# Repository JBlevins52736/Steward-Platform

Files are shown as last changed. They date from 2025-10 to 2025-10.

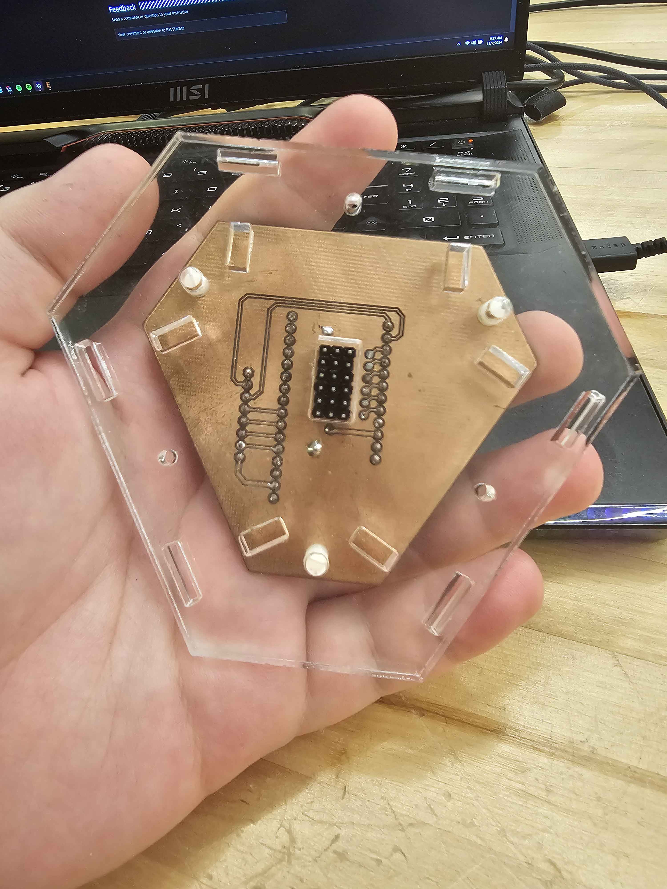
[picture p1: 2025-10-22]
media/images/20241107_091743.jpg

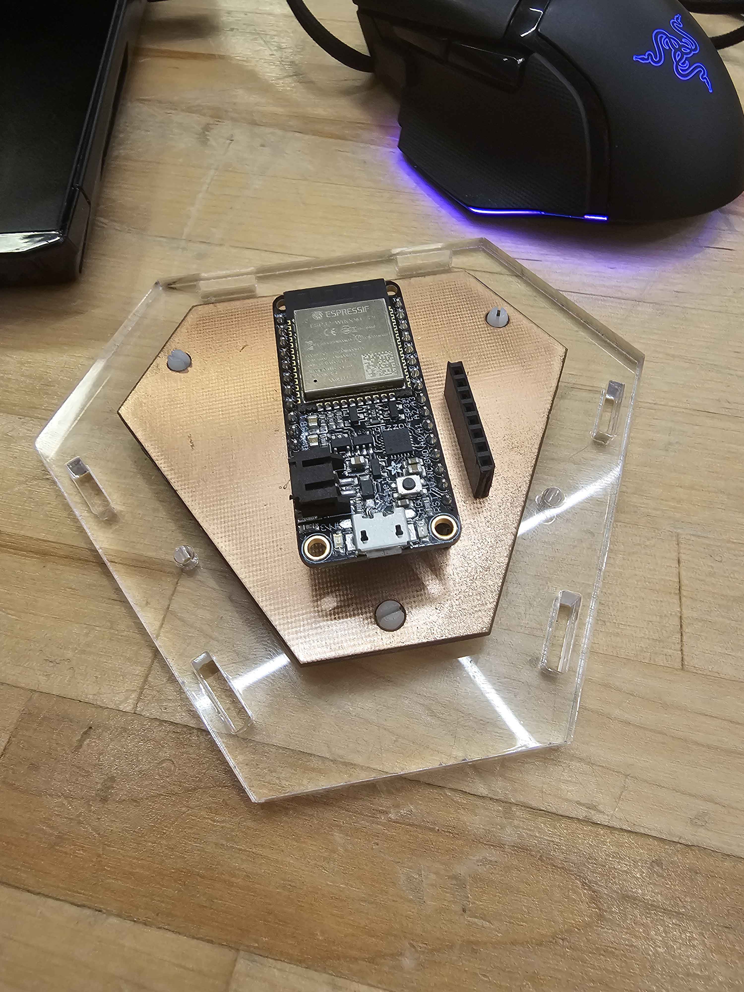
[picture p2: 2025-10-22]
media/images/20241107_091728.jpg

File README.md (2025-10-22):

# Stewart Platform - 6-DOF Parallel Manipulator

A mechanical design project for a Stewart Platform (Gough-Stewart platform) featuring 6 degrees of freedom motion using MG90S micro servo actuators.

## Overview

The Stewart Platform is a parallel manipulator with six prismatic actuators, commonly used in flight simulators, vehicle simulators, and precision positioning systems. This design provides full 6-DOF motion capability: translation along X, Y, Z axes and rotation around all three axes (roll, pitch, yaw).

## Project Structure

```
Steward-Platform/
├── cad/
│   ├── parts/          # Individual component parts (.SLDPRT)
│   ├── assemblies/     # Full assembly files (.SLDASM)
│   └── drawings/       # Technical drawings (.SLDDRW)
├── firmware/           # ESP32 Arduino code
├── electronics/        # Circuit board design files (EagleCAD/EasyEDA)
├── docs/               # Documentation and specifications
├── media/
│   ├── images/         # Renders, textures, and decals
│   ├── videos/         # Motion simulation videos
│   └── hdri/           # HDR environment maps for rendering
└── README.md
```

## Key Components

### Platform Structure
- **Top Plate** - Moving platform (upper)
- **Bottom Plate** - Fixed base (lower)
- **Middle Plate** - Intermediate structural support
- **Circuit Board** - Electronics mounting

### Actuation System
- **MG90S Micro Servos** (6x) - 9g hobby servos for actuation
- **Servo Horns** - Attachment points for linkages
- **Rods/Links** - Connecting elements between servos and platform
- **Ball Links** - Universal joints for full range of motion

### Electronics & Control
- **ESP32 Microcontroller** - Controls all 6 servos with 12 DOF motion patterns
- **Custom PCB** - Circuit board design available in `electronics/`
- **Firmware** - Arduino-based control code in `firmware/StewartPlatform.ino`

## Software Requirements

### CAD Software
- **SolidWorks** - Required to open and edit:
  - `.SLDPRT` - Part files
  - `.SLDASM` - Assembly files
  - `.SLDDRW` - Drawing files

### Firmware Development
- **Arduino IDE** with ESP32 board support
- **Required Libraries**:
  - ESP32Servo.h
- **Board Packages**:
  - `https://adafruit.github.io/arduino-board-index/package_adafruit_index.json`
  - `https://espressif.github.io/arduino-esp32/package_esp32_index.json`

### Electronics Design
- **EasyEDA** or compatible PCB design software for viewing/editing circuit board files

## Design Specifications

### Mechanical
- **Actuators**: 6x MG90S micro servos
- **Degrees of Freedom**: 6 (X, Y, Z, Roll, Pitch, Yaw)
- **Architecture**: Parallel manipulator (all actuators work together)
- **Joint Type**: Ball-and-socket/spherical joints
- **Servo Range**: 10° - 170° (configurable in firmware)

### Electronic
- **Controller**: ESP32 microcontroller
- **Servo Control**: 6 independent PWM channels
- **Motion Patterns**: 12 pre-programmed DOF states (Heave, Surge, Sway, Yaw, Pitch, Roll)
- **Calibration**: Individual servo trim adjustment via serial commands
- **Interpolation**: Smooth 500ms transitions between motion states

## Documentation

- `JB_SP_Measurement.xlsx` - Platform measurements and geometry specifications
- `StewartPlatformMotionStudyRubric.xlsx` - Motion study evaluation criteria
- `PrimaryDrawingtemplate.pdf` - Technical drawing template

## Motion Simulation

Motion studies and simulations are performed in SolidWorks Motion Analysis. Example simulation video available in `media/videos/`.

## Development

### Modifying the CAD Design
1. Open `cad/assemblies/JBJBStewardPlatform.SLDASM` in SolidWorks
2. Edit individual parts in the `cad/parts/` directory as needed
3. Verify assembly constraints maintain proper DOF
4. Run motion studies to validate range of motion
5. Update technical drawings if dimensions change
6. Export new servo positions to update firmware motion arrays

### Uploading Firmware
1. Install Arduino IDE with ESP32 board support (see Software Requirements)
2. Install required ESP32Servo library
3. Open `firmware/StewartPlatform.ino`
4. Connect ESP32 via USB
5. Select correct board and COM port
6. Upload to ESP32

### Serial Commands
The firmware supports serial commands for calibration:
- `C` - Get/set calibration mode (C=0 or C=1)
- `T` - Get/set trim for all servos (e.g., T=5)
- `T0` through `T5` - Get/set individual servo trim (e.g., T0=-3)
- `O` - Get/set platform offset (e.g., O=10)

### Best Practices
- Maintain proper assembly constraints for 6-DOF motion
- Verify no singularities in the workspace
- Keep ball joint positions within servo range
- Test full range of motion in simulation before fabrication
- Calibrate servo trim values before running motion sequences
- Use serial monitor at 115200 baud for debugging

## License

See repository license file for details.

## Contributing

Contributions, issues, and feature requests are welcome!

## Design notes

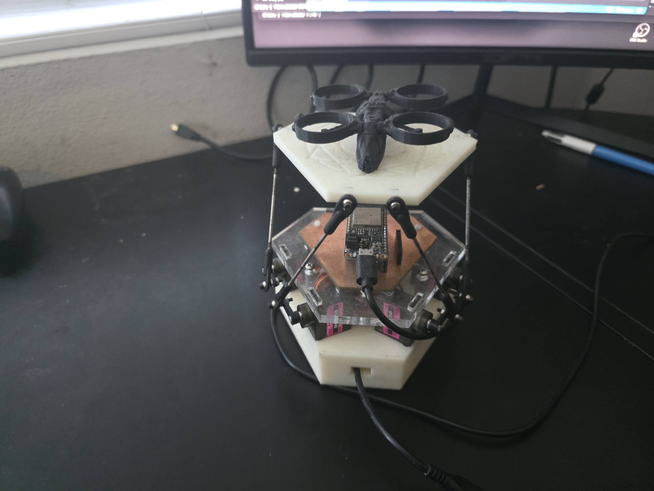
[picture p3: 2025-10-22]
media/images/Screenshot 2025-10-22 172505.png

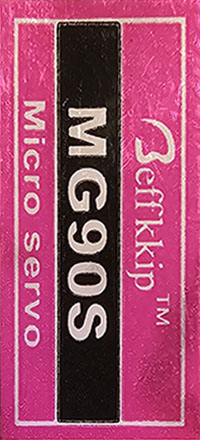
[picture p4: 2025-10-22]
media/images/mg90s micro servo decal.jpg

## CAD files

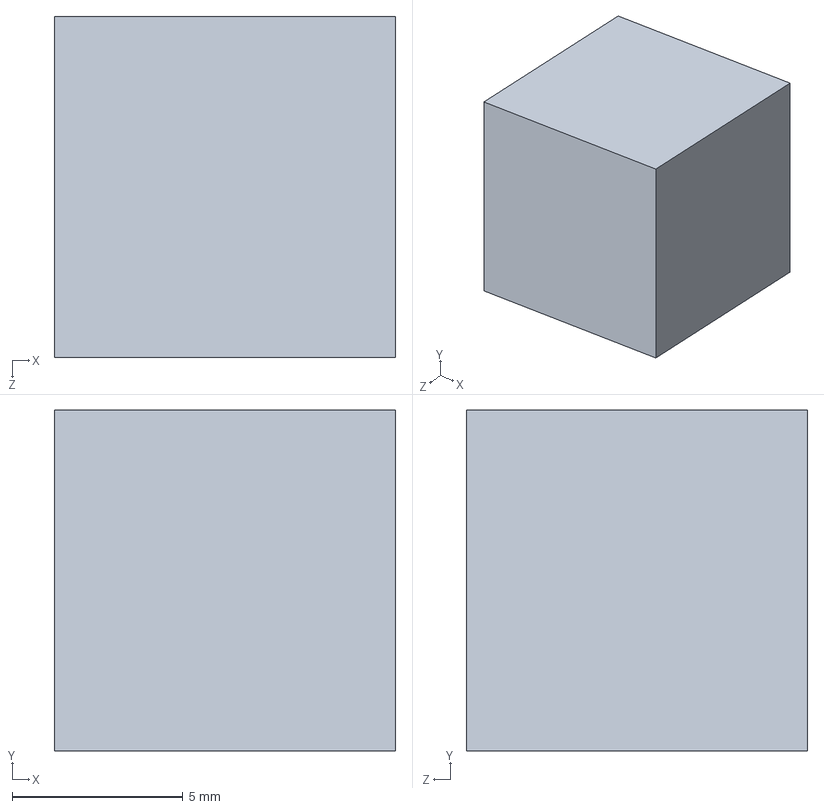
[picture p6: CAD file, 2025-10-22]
cad/parts/JB6dof.SLDPRT
10.0 x 10.00 x 10.0 mm

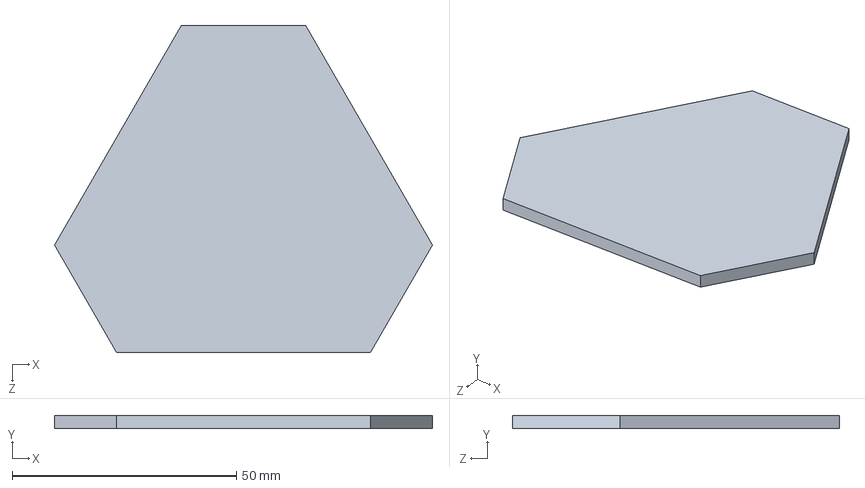
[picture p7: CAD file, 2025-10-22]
cad/parts/JBCircuit_board.SLDPRT
84.2 x 3.00 x 72.9 mm

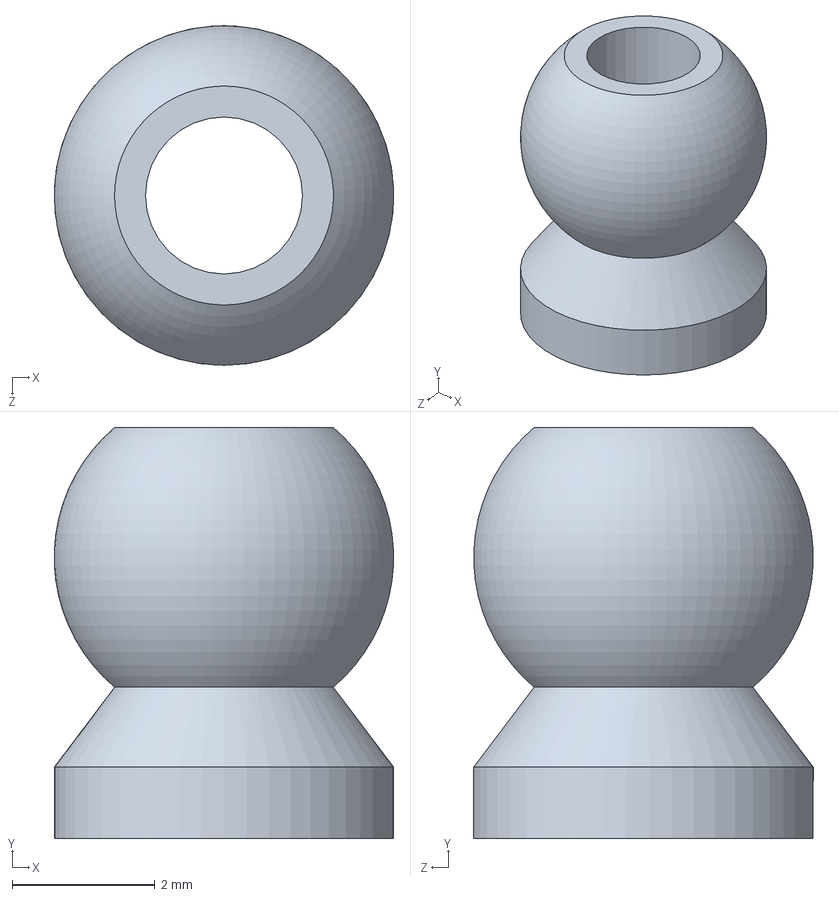
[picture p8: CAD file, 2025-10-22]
cad/parts/JBBalllink.SLDPRT
4.76 x 5.76 x 4.76 mm

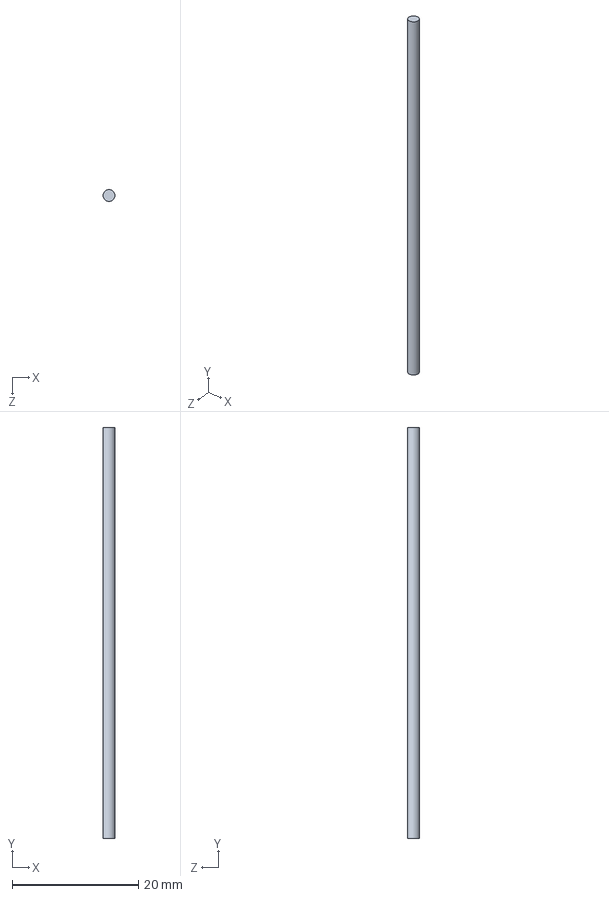
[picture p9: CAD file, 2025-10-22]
cad/parts/JBRod.SLDPRT
1.87 x 65.0 x 1.88 mm

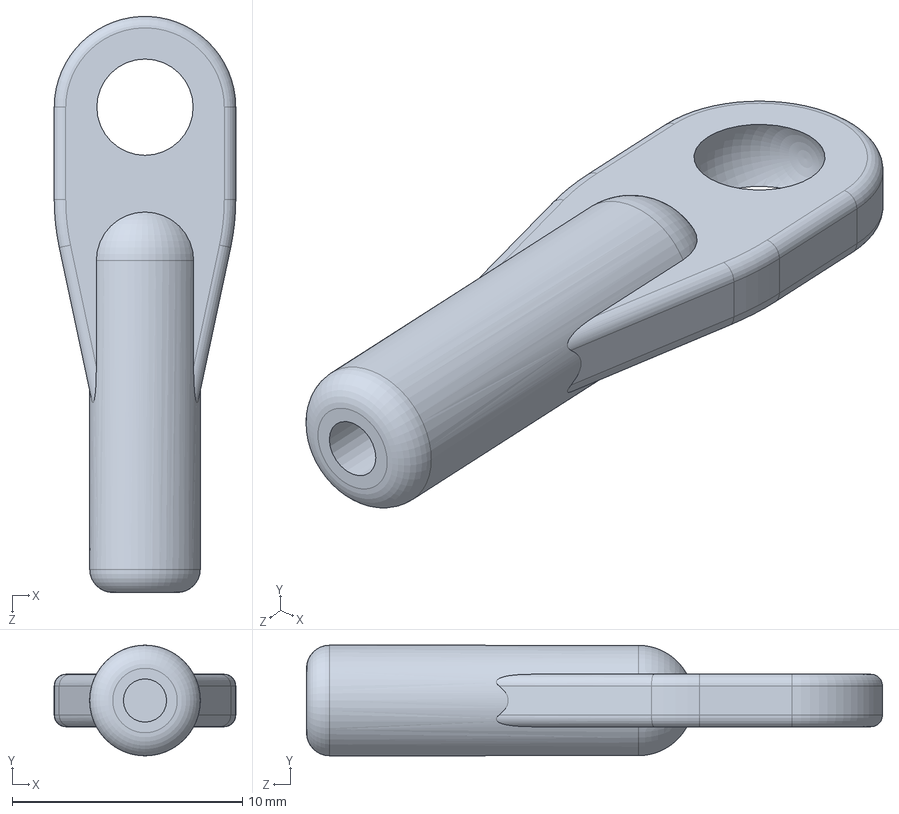
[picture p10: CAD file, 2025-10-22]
cad/parts/JBHousing.SLDPRT
7.88 x 4.80 x 25.0 mm

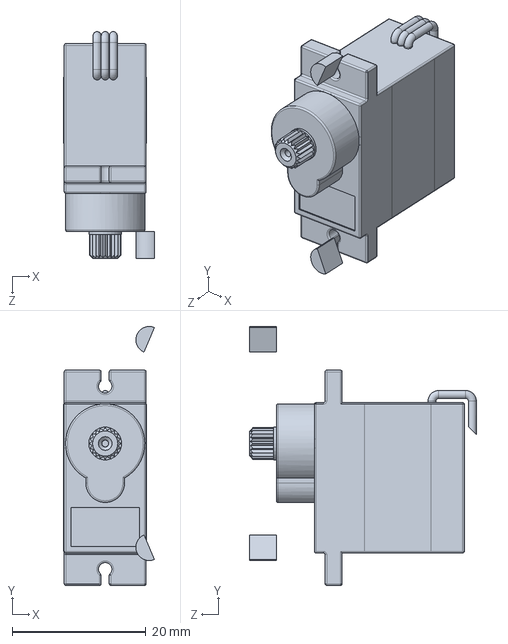
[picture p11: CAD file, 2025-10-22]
cad/parts/JBMG90S Micro Servo.SLDPRT
13.6 x 38.8 x 34.0 mm

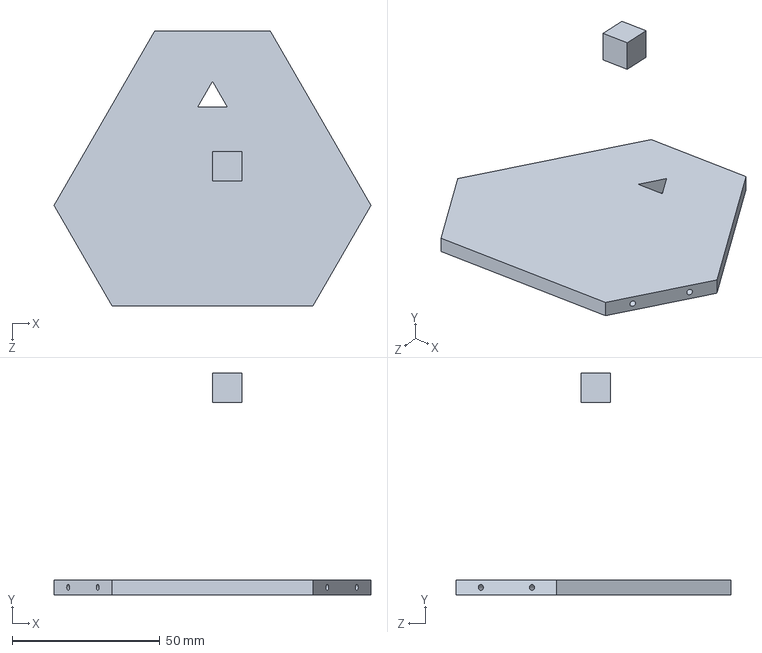
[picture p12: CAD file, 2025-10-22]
cad/parts/JBTop_Plate.SLDPRT
107.3 x 75.0 x 92.9 mm

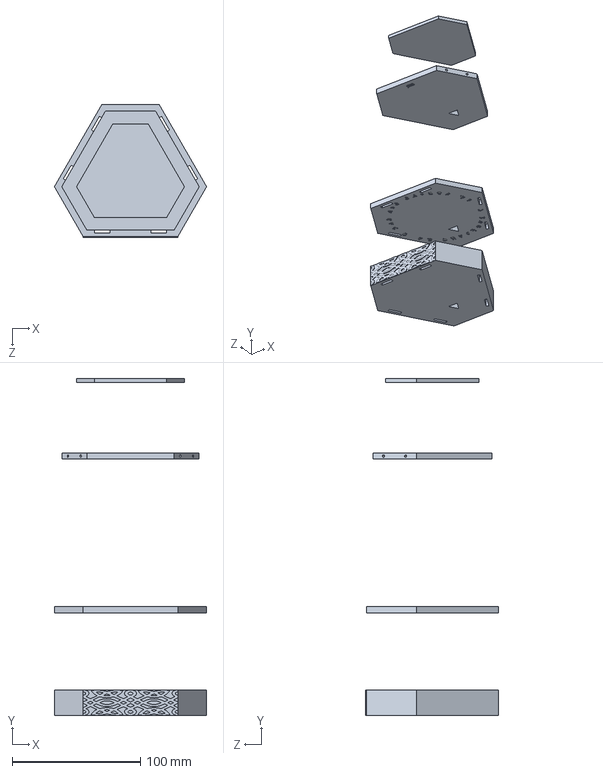
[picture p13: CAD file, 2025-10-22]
cad/parts/JBMASTER.SLDPRT
118.8 x 263.0 x 103.4 mm

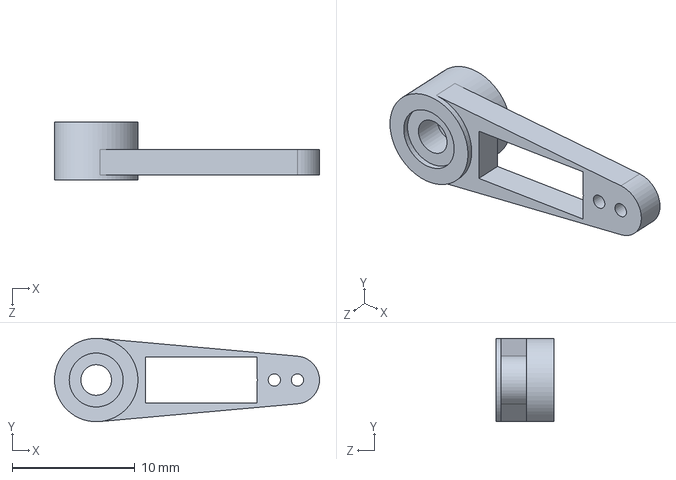
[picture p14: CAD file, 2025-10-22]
cad/parts/JBHorn (MG90S).SLDPRT
21.6 x 6.80 x 4.75 mm

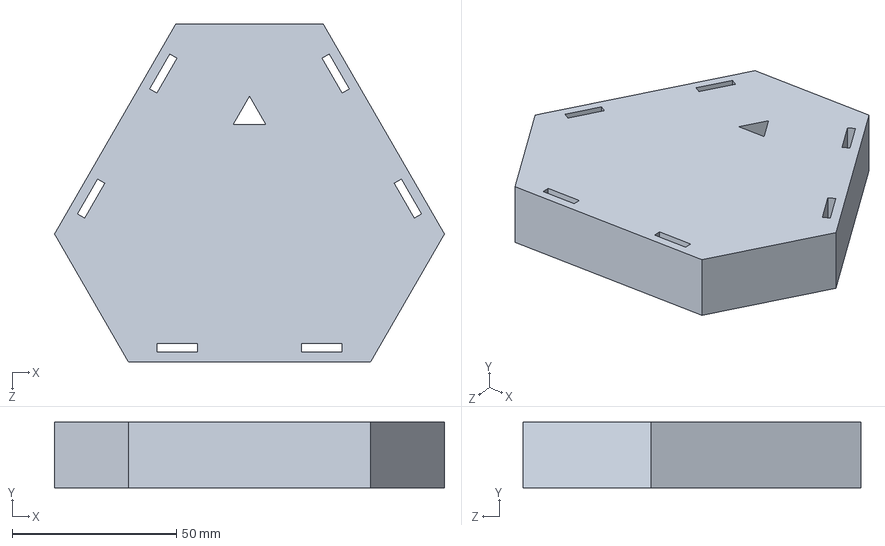
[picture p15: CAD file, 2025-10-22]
cad/parts/JBBottem_Plate.SLDPRT
118.8 x 20.0 x 102.9 mm

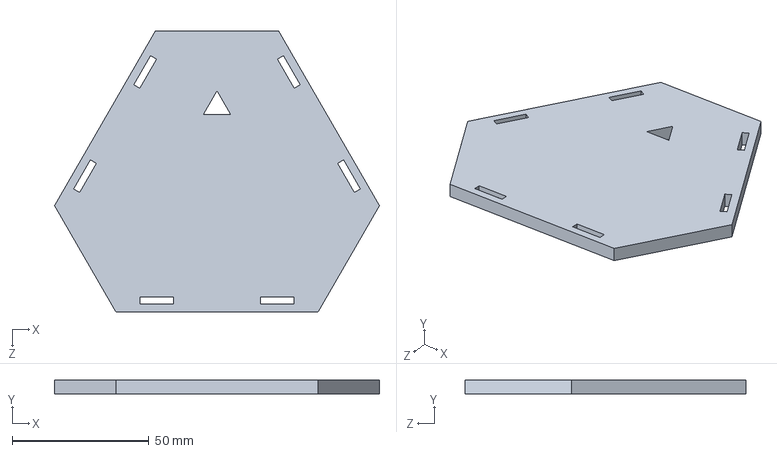
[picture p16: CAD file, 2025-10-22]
cad/parts/JBMiddle_Plate.SLDPRT
118.8 x 5.00 x 102.9 mm

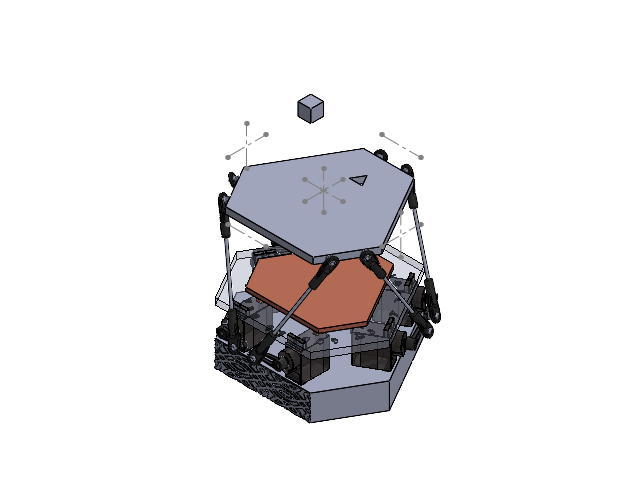
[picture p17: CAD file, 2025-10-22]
cad/assemblies/JBJBStewardPlatform.SLDASM
Bottem_Plate
Middle_Plate
Top_Plate
MG90S Micro Servo x 6
Balllink x 12
Rod x 6
Housing x 12
Horn (MG90S) x 6
6dof
Circuit_board

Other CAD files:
cad/drawings/JBJBStewardPlatform.SLDDRW

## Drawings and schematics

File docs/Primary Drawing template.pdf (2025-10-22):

B B

2

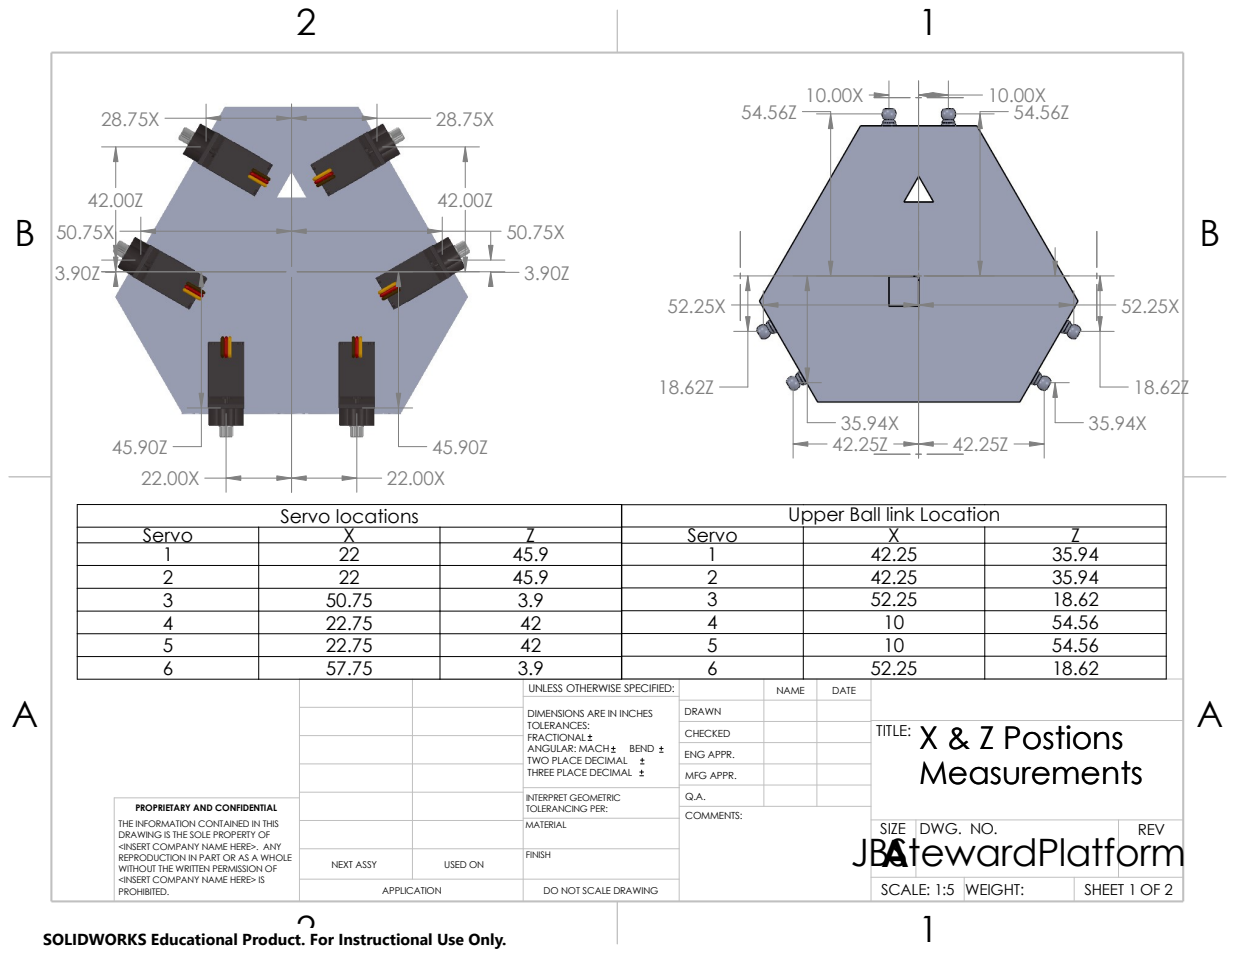
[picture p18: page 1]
COMMENTS:

Servo locations | Upper Ball link Location

Servo | X | Z | Servo | X | Z
1 | 22 | 45.9 | 1 | 42.25 | 35.94
2 | 22 | 45.9 | 2 | 42.25 | 35.94
3 | 50.75 | 3.9 | 3 | 52.25 | 18.62
4 | 22.75 | 42 | 4 | 10 | 54.56
5 | 22.75 | 42 | 5 | 10 | 54.56
6 | 57.75 | 3.9 | 6 | 52.25 | 18.62

UNLESS OTHERWISE SPECIFIED: | | NAME | DATE

DIMENSIONS ARE IN INCHES TOLERANCES: FRACTIONAL ANGULAR: MACH BEND TWO PLACE DECIMAL THREE PLACE DECIMAL | DRAWN

CHECKED | | | X & Z Postions TITLE: Measurements

ENG APPR.
MFG APPR.

INTERPRET GEOMETRIC TOLERANCING PER: | Q.A.
MATERIAL | JBStewardPlatform | SIZE A | DWG. NO. | REV

PROPRIETARY AND CONFIDENTIAL
THE INFORMATION CONTAINED IN THIS
DRAWING IS THE SOLE PROPERTY OF
<INSERT COMPANY NAME HERE>. ANY
REPRODUCTION IN PART OR AS A WHOLE
WITHOUT THE WRITTEN PERMISSION OF
<INSERT COMPANY NAME HERE> IS
PROHIBITED.

NEXT ASSY | USED ON | FINISH

APPLICATION | DO NOT SCALE DRAWING | | SCALE: 1:5 | WEIGHT: | SHEET 1 OF 2

SOLIDWORKS Educational Product. For Instructional Use Only.

124.38

# Center of Ball Joints

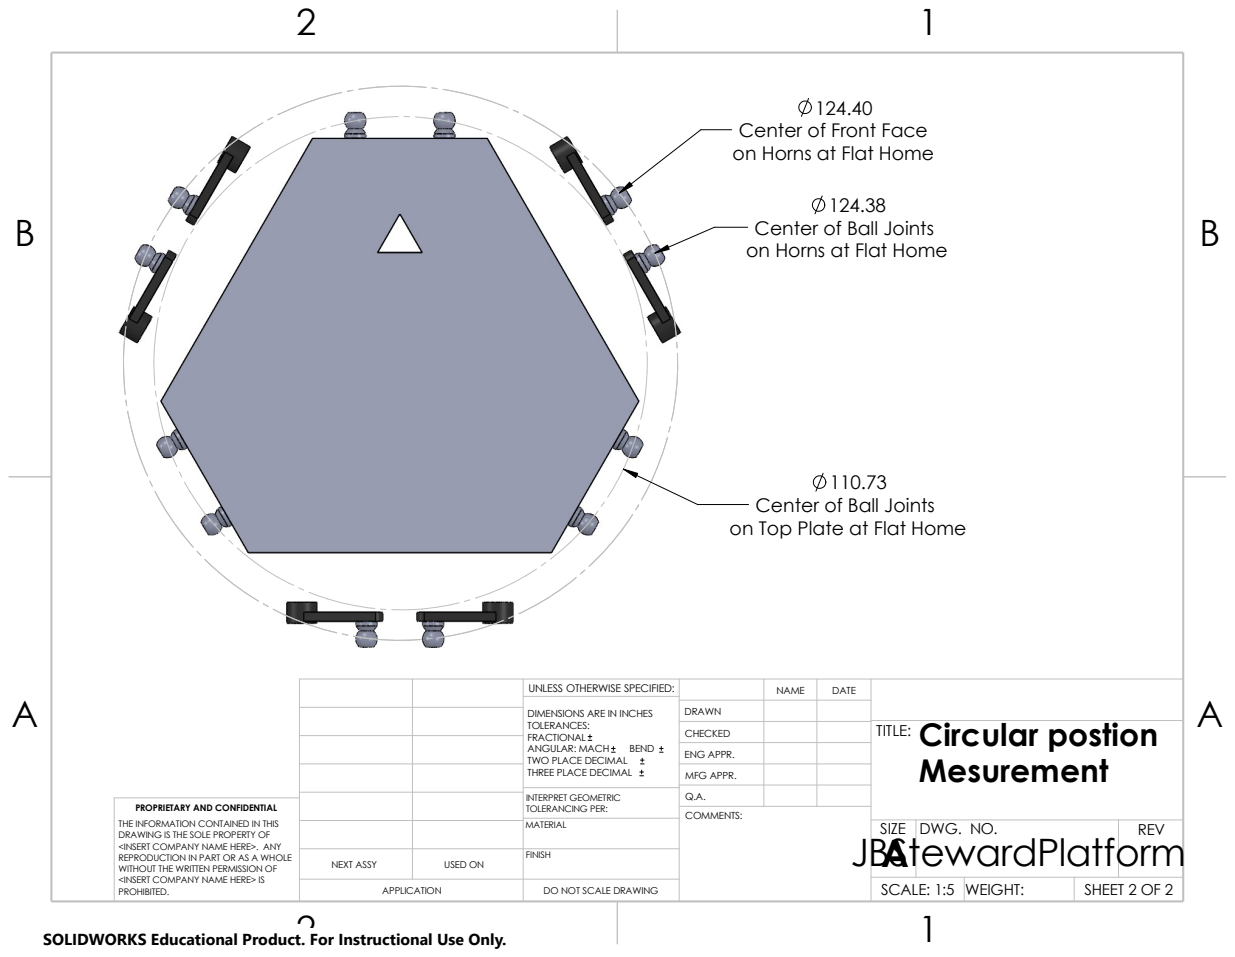
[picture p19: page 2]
COMMENTS:

Center of Front Face
on Horns at Flat Home

Center of Ball Joints
on Top Plate at Flat Home

UNLESS OTHERWISE SPECIFIED: | | NAME | DATE

DIMENSIONS ARE IN INCHES TOLERANCES: FRACTIONAL ANGULAR: MACH BEND TWO PLACE DECIMAL THREE PLACE DECIMAL | DRAWN

CHECKED | | | Circular postion TITLE: Mesurement

ENG APPR.
MFG APPR.

INTERPRET GEOMETRIC TOLERANCING PER: | Q.A.
MATERIAL | JBStewardPlatform | SIZE A | DWG. NO. | REV

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

NEXT ASSY | USED ON | FINISH

APPLICATION | DO NOT SCALE DRAWING | | SCALE: 1:5 | WEIGHT: | SHEET 2 OF 2

SOLIDWORKS Educational Product. For Instructional Use Only.

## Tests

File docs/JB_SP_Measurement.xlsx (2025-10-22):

 | NO COLLISION |  |  |  |  |  |  |  |  | COLLISION
 | Heave(Y) | Surge(Z) | Sway(X) | Yaw(Y) | Pitch(X) | Roll(Z) |  |  |  | Heave(Y) | Surge(Z) | Sway(X) | Yaw(Y) | Pitch(X) | Roll(Z)
 | 14.3 | 22.66 | 21.6 | 22.79 | 14.5 | 15 |  |  |  | 13.85 | 22.66 | 20.6 | 21.35 | 14.6 | 12.7
Home | 0 | 0 | 0 | 0 | 0 | 0 |  |  | Home | 0 | 0 | 0 | 0 | 0 | 0 |  |  | 61.85
 | 15.86 | 24.4 | 21.6 | 22.79 | 16.67 | 15 |  |  |  | 11.5 | 21.4 | 20.6 | 21.35 | 11.9 | 12.7
Symmetry | SYM |  | SYM | SYM |  | SYM |  |  |  | SYM |  | SYM | SYM |  | SYM
 |  |  |  |  |  |  |  |  |  |  | check nb |  |  | check nb
 | OFFSET | 23.01
Angled Home |  | Heave |  |  |  | Surge |  |  |  | Sway |  |  |  | Yaw |  |  |  | Pitch |  |  |  | Roll
Servo | Start Angle | 1 | 2 | 3 | 4 | 5 | 6 | 7 | 8 | 9 | 10 | 11 | 12 | 13 | 14 | 15 | 16 | 17 | 18 | 19 | 20 | 21 | 22 | 23 | 24
1 | 90 | 25.35 |  | 135.82 |  | 64.67 |  | 125.91 |  | 135.26 |  | 73.6 |  | 59.86 |  | 152.27 |  | 59.38 |  | 118.09 |  | 124.79 |  | 51.38
2 | 90 | 154.65 |  | 44.18 |  | 132.98 |  | 113.03 |  | 44.74 |  | 106.32 |  | 121.14 |  | 125.02 |  | 120.62 |  | 61.91 |  | 128.5 |  | 55.11
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

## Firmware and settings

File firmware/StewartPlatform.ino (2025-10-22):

/****
Required Arduino hardware packages:
https://adafruit.github.io/arduino-board-index/package_adafruit_index.json
https://espressif.github.io/arduino-esp32/package_esp32_index.json

Required Libraries:
Arduino ESP32Servo.h

****/

// includes
#include <ESP32Servo.h>

// macros
#define NUM_SERVOS 6
#define MIN_SERVO_POS 10
#define MID_SERVO_POS 90
#define MAX_SERVO_POS 170
#define TIMESTAMP_PERIOD 500
#define NUM_PLATFORM_STATES 24

// structs
typedef struct 
{
  uint8_t pin;
  int8_t trim;
  float offset;
  uint8_t last;
  uint8_t next;
} SERVO_DATA;

// globals
bool calibrate = false;
uint32_t timestamp = 0;
int8_t platform_offset = 0;
uint8_t platform_state = 0;

/*****************/
/**** TODO #1 ****/
/*****************/

// create/initialize 6x array of servo objects
Servo servos[NUM_SERVOS];

// create/initialize 6x array of SERVO_DATA (pin=?, trim=0, last=90, next=90)
SERVO_DATA sdat[NUM_SERVOS] = {
  {pin: 14, trim: 7, offset:-23.01, last: MID_SERVO_POS, next: MID_SERVO_POS},
  {pin: 32, trim: -7, offset:23.01, last: MID_SERVO_POS, next: MID_SERVO_POS},
  {pin: 15, trim: 6, offset:-23.01, last: MID_SERVO_POS, next: MID_SERVO_POS},
  {pin: 33, trim: 0, offset:23.01, last: MID_SERVO_POS, next: MID_SERVO_POS},
  {pin: 27, trim: 10, offset:-23.01, last: MID_SERVO_POS, next: MID_SERVO_POS},
  {pin: 12, trim: 3, offset:23.01, last: MID_SERVO_POS, next: MID_SERVO_POS}
};

// create/initialize 24x6 array of DOF platform positions from Solidworks simulation (heave, surge, sway, yaw, pitch, roll)
float platform_positions[NUM_PLATFORM_STATES][NUM_SERVOS] = {
  
   // Initial state (Home position for all servos)
  // {60, 60, 60, 60, 60, 60},
  // {90, 90, 90, 90, 90, 90},
  // {120, 120, 120, 120, 120, 120}

  // Heave positions 
  {25.35, 154.65, 25.35, 154.65, 25.35, 154.65}, // State 1
  {90, 90, 90, 90, 90, 90}, 
  {135.82, 44.18, 135.82, 44.18, 135.82, 44.18}, // State 2
  {90, 90, 90, 90, 90, 90},
  // Surge positions 
   {73.49, 132.98, 125.68, 83.79, 96.21, 22.11}, // State 3
   {90, 90, 90, 90, 90, 90}, 
   {137.74, 42.26, 22.17, 62.49, 117.51, 125.68}, // State 4
   {90, 90, 90, 90, 90, 90}, 

  // Sway positions
  {64.21, 45.35, 85.14, 121.15, 150.44, 108.64},  // State 5
  {90, 90, 90, 90, 90, 90}, 
  {135.65, 115.79, 108.64, 29.56, 58.85, 85.14},    // State 6
  {90, 90, 90, 90, 90, 90}, 

  // Yaw positions 
  {115.79, 121.14, 115.79, 121.14, 115.79, 121.14},   // State 7
  {90, 90, 90, 90, 90, 90}, 
  {27.73, 54.98, 27.73, 54.98, 27.73, 54.98}, // State 8
  {90, 90, 90, 90, 90, 90}, 
  

  // Pitch positions
  {58.68, 121.32, 70.94, 24.43, 152.04, 109.06}, // State 9
  {90, 90, 90, 90, 90, 90}, 
  {118.09, 61.91, 104.18, 136.99, 43.12, 75.82},  // State 10
  {90, 90, 90, 90, 90, 90}, 

  // Roll positions 
  {124.79, 128.5, 45.19, 95.94, 97.36, 42.57},    // State 11
  {90, 90, 90, 90, 90, 90}, 
  {51.38, 55.11, 137.61, 82.62, 84.05, 134.96},   // State 12
  {90, 90, 90, 90, 90, 90}  
};
// process KVP (KEY=VAL)
String procKVP(String skvp)
{
  String sret;
	bool rv = true;

	if (skvp.length())
	{
    skvp.toUpperCase();

		int16_t z = skvp.indexOf("=");
    if (z == -1) z = skvp.length();
		String skey = skvp.substring(0, z);
		String sval = skvp.substring(z + 1);
		uint32_t ival = sval.toInt();
		float fval = sval.toFloat();

		//****************************//
		//***** sval length == 0 *****//
		//****************************//
		if (sval.length() == 0)
		{
      // set calibration mode
			if (skey == "C") sval = String(calibrate);

      // print trim all servos
      else if (skey == "T")
      {
        for (uint8_t i = 0; i < NUM_SERVOS; i++)
        {
          sval += " ";
          sval += String(sdat[i].trim);
        }
      }

      // print trim specific servo
      else if (skey[0] == 'T')
      {
        int8_t i = skey[1] - 48;
        if ((i  < 0) || (i >= NUM_SERVOS)) rv = false;
        else sval = String(sdat[i].trim);
      }

      // print offset all servos
      else if (skey == "O") sval  = String(platform_offset);

      // else error
			else rv = false;
		}

		//*********************************//
		//***** else sval length != 0 *****//
		//*********************************//

    // set calibration state
    else if (skey == "C") calibrate = ival;

    // set trim all servos
    else if (skey == "T") {for (uint8_t i = 0; i < NUM_SERVOS; i++) sdat[i].trim = ival;}

    // set trim specific servo
    else if (skey[0] == 'T')
    {
      int8_t i = skey[1] - 48;
      if ((i  < 0) || (i >= NUM_SERVOS)) rv = false;
      else sdat[i].trim = ival;
    }

    // set offset all servos
    else if (skey == "O") platform_offset = ival;

    // else error
		else rv = false;

    // if command OK
		if (rv == true)
		{
			if (sval.length()) sret = skey + "=" + sval + " OK";
			else sret = skey + " OK";
		}

    // else command ER
    else sret = skvp + " ER";

    Serial.println(sret);
	}

	return(sret);
}

// read KVP
String readKVP(void)
{
	bool rv = false;
	static uint8_t x = 0;
	static String sstr = "";

	if (x == 0) sstr = "";

	while (Serial.available())
	{
		char c = (char)Serial.read();
		if ((c == '\r') || (c == '\n'))
		{
			x = 0;
			rv = true;
			break;
		}

		x++;
		sstr += c;
	}

	return(rv ? sstr : String(""));
}

void setup()
{
  
  /*****************/
  /**** TODO #2 ****/
  /*****************/
  
  // initialize serial object
  Serial.begin(115200);
  
  // wait for terminal to open
  while(!Serial || (millis() <= 5000));
 

  // Attach each servo to its corresponding pin and set to MID_SERVO_POS (90 degrees)
  for (int i = 0; i < NUM_SERVOS; i++) {
    servos[i].attach(sdat[i].pin);      
    servos[i].write(MID_SERVO_POS+sdat[i].trim  + sdat[i].offset);     

  Serial.println("setup() complete");
}

void loop()
{
  // capture timenow in milliseconds
    uint32_t timenow = millis();
  // process commands
  procKVP(readKVP());
  
  /*****************/
  /**** TODO #3 ****/
  /*****************/

  // if calibrating servo trim
  if (calibrate) 
  {
	   for (int i = 0; i < NUM_SERVOS; i++) {
      // Set servo position to 90 degrees plus its trim value, constrained to the defined limits
      float pos = constrain(MID_SERVO_POS + sdat[i].trim - sdat[i].offset , MIN_SERVO_POS, MAX_SERVO_POS);
      servos[i].write(pos);
    }
    return;
  }

  /*****************/
  /**** TODO #5 ****/
  /*****************/

  // calculate ratio of timenow to timestamp relative 500ms period
  // for all servos
    // calculate lerped position between last and next using ratio
    // write servo to lerped position, use contrain() to limit range.
  float ratio = float(timenow - timestamp) / TIMESTAMP_PERIOD;


  // Print the interpolation ratio for debugging
  Serial.print("Interpolation ratio: ");
  Serial.println(ratio);

  for (int i = 0; i < NUM_SERVOS; i++) {
    float pos = sdat[i].last + ratio * (sdat[i].next - sdat[i].last);
    pos = constrain(pos, MIN_SERVO_POS, MAX_SERVO_POS);
    servos[i].write(pos);

  // Debugging information for interpolated position
    Serial.print("Servo ");
    Serial.print(i);
    Serial.print(" position: ");
    Serial.println(pos - sdat[i].trim);
  }
  /*****************/
  /**** TODO #4 ****/
  /*****************/

  // create timestamp that triggers every 500ms
	// reset timestamp to timenow
	// set next platform state (0..23..etc)
	// for all servos
	  // save servo next position to servo last position
	  // set servo next position to platform position for state, plus servo trim value
// Calculate the ratio for interpolation over the 500 ms period
  
  if (timenow - timestamp >= TIMESTAMP_PERIOD) {
   
    timestamp = timenow;

    
    platform_state = (platform_state + 1) % NUM_PLATFORM_STATES;

    for (int i = 0; i < NUM_SERVOS; i++) {
      
      sdat[i].last = sdat[i].next;

      sdat[i].next = platform_positions[platform_state][i] + sdat[i].trim - sdat[i].offset ;
    }
  }


  
}

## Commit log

2025-10-22 Initial commit: Stewart Platform 6-DOF mechanical design
    - Add organized project structure with cad/, docs/, and media/ directories
    - Include SolidWorks parts, assemblies, and technical drawings
    - Add comprehensive README with project overview and specifications
    - Add .gitignore for SolidWorks temporary files and large media
    [JB6dof.SLDPRT, JBBalllink.SLDPRT, JBBottem_Plate.SLDPRT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]
2025-10-22 Add firmware and electronics components
    - Add ESP32 Arduino firmware for 6-servo control
    - Include 12 pre-programmed DOF motion patterns (Heave, Surge, Sway, Yaw, Pitch, Roll)
    - Add serial calibration commands for servo trim adjustment
    - Add EasyEDA circuit board design files
    - Add platform build photos
    - Update README with firmware setup and serial command documentation
    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
